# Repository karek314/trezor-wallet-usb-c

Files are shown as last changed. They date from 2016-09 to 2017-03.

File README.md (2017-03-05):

# Trezor Wallet USB-C
USB-C version of trezor hardware wallet designed to a bigger case

This is hardware project of forked <a href="https://github.com/trezor/trezor-hw">trezor-hw repository</a> redesigned to work with USB-C and a little bigger case.

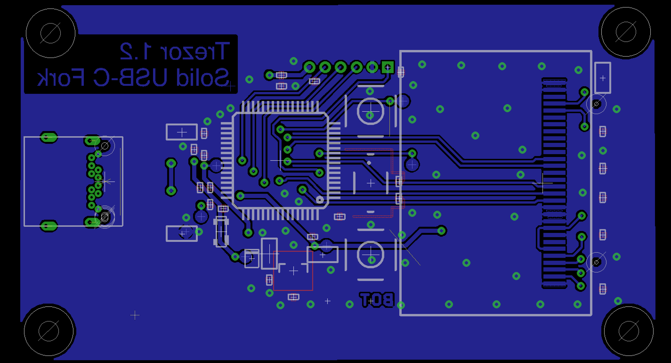
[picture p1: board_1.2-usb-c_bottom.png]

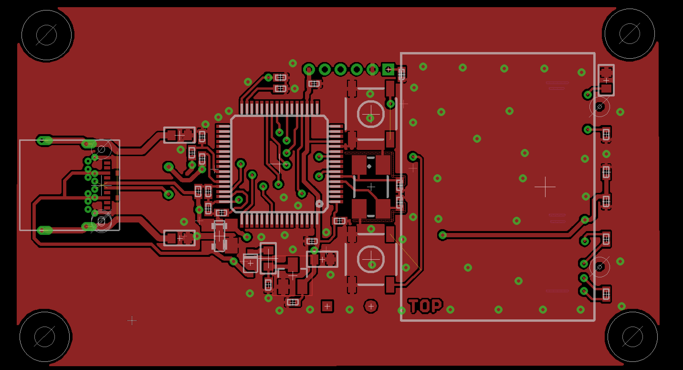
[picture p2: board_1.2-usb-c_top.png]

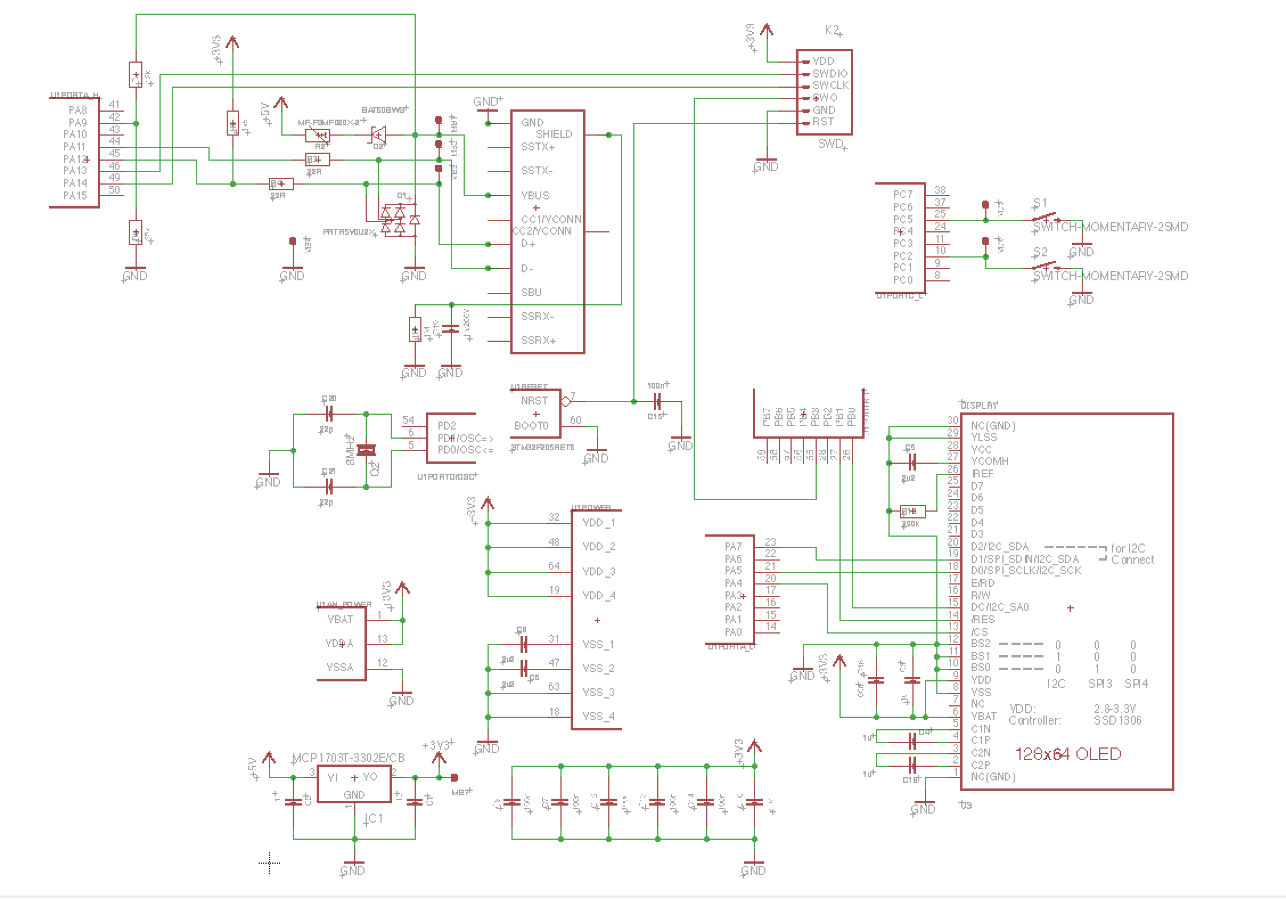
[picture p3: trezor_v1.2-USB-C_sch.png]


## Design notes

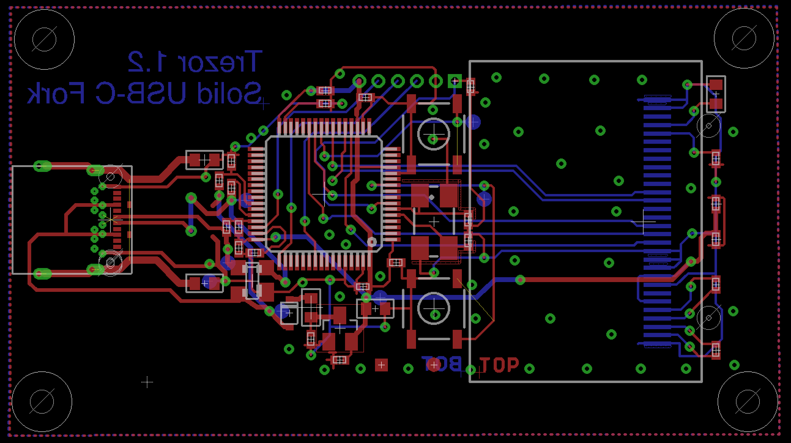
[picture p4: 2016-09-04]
trezor_v1.2-USB-C.png

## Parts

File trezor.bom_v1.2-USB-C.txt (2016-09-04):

Trezor
======

- 5x SMD 0603 Capacitor 1uF - C1, C2, C4, C10, C11
- 7x SMD 0603 Capacitor 0.1uF - C3, C12, C13, C14, C15, C16, C18
- 3x SMD 0603 Capacitor 2.2uF - C6, C7, C17
- 1x SMD 0603 Capacitor 4.7uF - C5
- 2x SMD 0603 Capacitor 22pF - C8, C9

- 1x SMD 0603 Resistor 390k - R1

- 2x Microbuton P-B17310
  * http://www.gme.cz/mikrospinace-do-dps/p-b17310-p630-143/

- 1x Micro USB (type B) Receptacle Bottom
  * http://cz.farnell.com/molex/47346-0001/micro-usb-type-b-receptacle-bottom/dp/1568026

- 1x OLED display 128x64 UG-2864HSWEG01
  * http://www.wide.hk/products.php?product=128X64-OLED-LED-Display-Module-SSD1306-%28White-Color%29

- 1x STM32F205RE
  * http://www.st.com/web/catalog/mmc/FM141/SC1169/SS1575/LN1433/PF245096
  * http://cz.farnell.com/stmicroelectronics/stm32f205ret6/ic-mcu-32bit-arm-64-lqfp/dp/2060897

- 1x MCP1703 Low Dropout Voltage Regulator
  * http://www.microchip.com/wwwproducts/Devices.aspx?dDocName=en530838
  * http://cz.farnell.com/microchip/mcp1703t-3302e-cb/v-reg-ldo-250ma-3-3v-sot-23a-3/dp/1439518

- 1x ABMM2 8 MHz Crystal
  * http://cz.farnell.com/abracon/abmm2-8-000mhz-e2-t/crystal-8m-18pf-cl-6x3-6mm-smt/dp/1611803

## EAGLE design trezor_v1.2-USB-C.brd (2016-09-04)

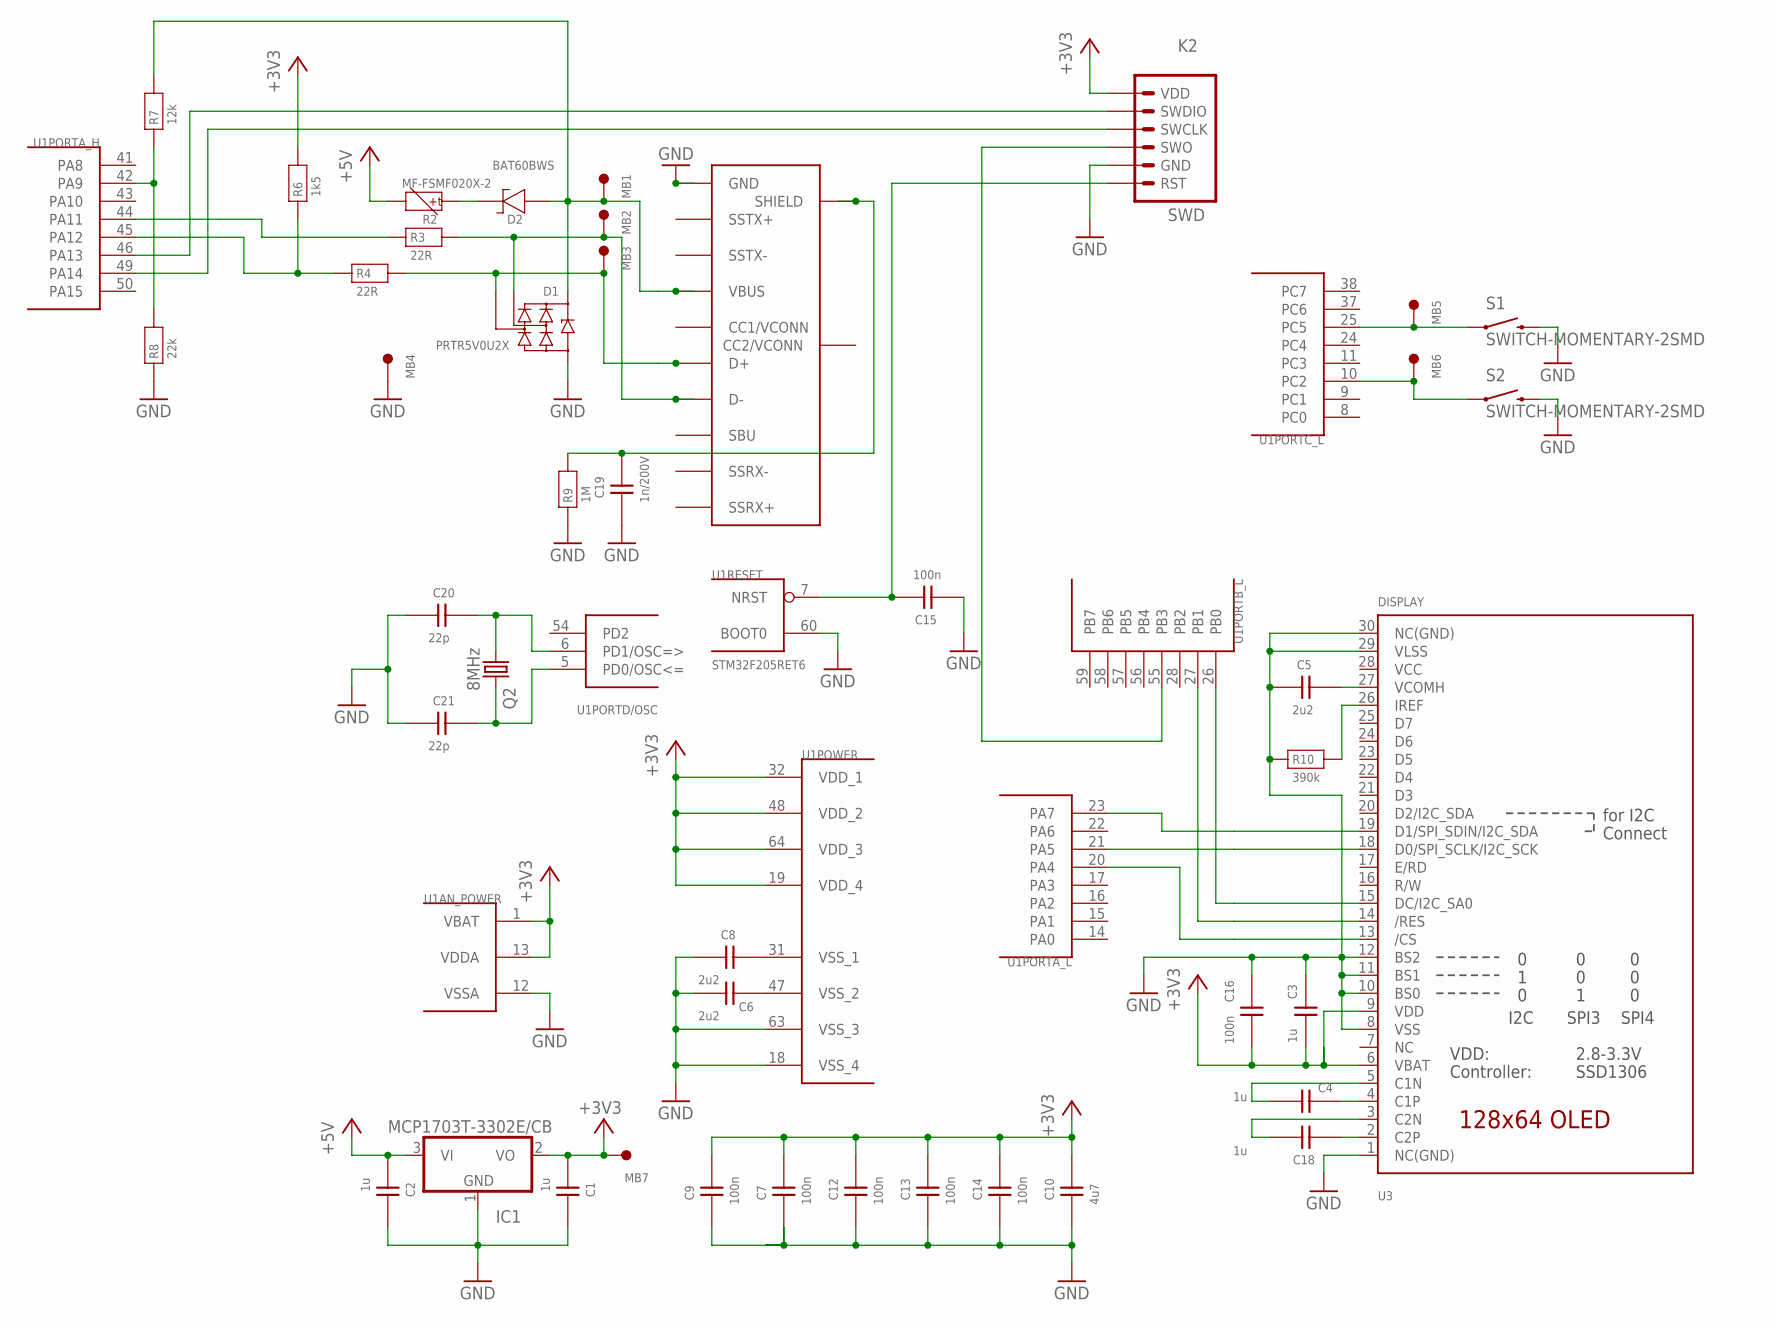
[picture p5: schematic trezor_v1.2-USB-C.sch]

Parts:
C1, C2, C3, C4, C18: 1u; 0402
C5: 2u2; 0603
C6, C8: 2u2; 0402
C7, C9, C12, C13, C14, C15, C16: 100n; 0402
C10: 4u7; 0603
C19: 1n/200V; 0603
C20, C21: 22p; 0402
D1: PRTR5V0U2X; SOT143B
D2: BAT60BWS; SOD323
IC1: MCP1703T-3302E/CB; SOT23
K2: SWD
MB1, MB2, MB3, MB4, MB5, MB6, MB7: MB_1.50; MB1.5
Q2: 8MHz; CTS406
R2: MF-FSMF020X-2; 0603
R3, R4: 22R; 0402
R6: 1k5; 0402
R7: 12k; 0402
R8: 22k; 0402
R9: 1M; 0603
R10: 390k; 0402
S1, S2: SWITCH-MOMENTARY-2SMD; TACTILE_SWITCH_SMD
U1: STM32F205RET6; TQFP64
U3: DISPLAY; UG-2864HSWEG01_0.96IN_WRAPAROUND
U$1: USB-TYPE-CHYBRID; USB-TYPE-C-HYBRID

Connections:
+3V3: C1.P$1 (1), C3.P$1 (1), C7.P$2 (2), C9.P$2 (2), C10.2, C12.P$2 (2), C13.P$2 (2), C14.P$2 (2), C16.P$1 (1), IC1.2 (VO), K2.6 (VDD), MB7.1, R6.P$2 (2), U1.1 (VBAT), U1.13 (VDDA), U1.19 (VDD_4), U1.32 (VDD_1), U1.48 (VDD_2), U1.64 (VDD_3), U3.6 (VBAT), U3.9 (VDD)
+5V: C2.P$1 (1), IC1.3 (VI), R2.2
GND: C1.P$2 (2), C2.P$2 (2), C3.P$2 (2), C5.1, C6.P$1 (1), C7.P$1 (1), C8.P$1 (1), C9.P$1 (1), C10.1, C12.P$1 (1), C13.P$1 (1), C14.P$1 (1), C15.P$1 (1), C16.P$2 (2), C19.1, C20.P$1 (1), C21.P$1 (1), D1.1 (GND), IC1.1 (GND), K2.2 (GND), MB4.1, R8.P$1 (1), R9.1, R10.P$1 (1), S1.3 (2), S1.4 (2), S2.3 (2), S2.4 (2), U1.12 (VSSA), U1.18 (VSS_4), U1.60 (BOOT0), U1.63 (VSS_3), U3.1 (NC(GND)), U3.8 (VSS), U3.10 (BS0), U3.11 (BS1), U3.12 (BS2), U3.29 (VLSS), U3.30 (NC(GND)), U$1.1 (GND), U$1.12 (GND), U$1.B1 (GND), U$1.B12 (GND)
unnamed: U1.23 (PA7), U3.19 (D1/SPI_SDIN/I2C_SDA)
unnamed: C15.P$2 (2), K2.1 (RST), U1.7 (NRST)
unnamed: U1.26 (PB0), U3.15 (DC/I2C_SA0)
unnamed: C8.P$2 (2), U1.31 (VSS_1)
unnamed: U1.21 (PA5), U3.18 (D0/SPI_SCLK/I2C_SCK)
unnamed: C5.2, U3.27 (VCOMH)
unnamed: U1.27 (PB1), U3.14 (/RES)
unnamed: C6.P$2 (2), U1.47 (VSS_2)
unnamed: R10.P$2 (2), U3.26 (IREF)
unnamed: C18.P$1 (1), U3.2 (C2P)
unnamed: C4.P$1 (1), U3.4 (C1P)
unnamed: C18.P$2 (2), U3.3 (C2N)
unnamed: C4.P$2 (2), U3.5 (C1N)
unnamed: K2.3 (SWO), U1.55 (PB3)
unnamed: K2.5 (SWDIO), U1.46 (PA13)
unnamed: U1.20 (PA4), U3.13 (/CS)
unnamed: K2.4 (SWCLK), U1.49 (PA14)
unnamed: R3.P$1 (1), U1.44 (PA11)
unnamed: MB5.1, S1.1, S1.2 (1), U1.25 (PC5)
unnamed: MB6.1, S2.1, S2.2 (1), U1.10 (PC2)
unnamed: D2.K (2), R2.1
unnamed: D1.2 (I/O1), MB2.1, R3.P$2 (2), U$1.7 (D-), U$1.B7 (D-)
unnamed: D1.3 (I/O2), MB3.1, R4.P$2 (2), U$1.6 (D+), U$1.B6 (D+)
unnamed: C19.2, R9.2, U$1.P$1 (SHIELD), U$1.P$2 (SHIELD), U$1.P$3 (SHIELD), U$1.P$4 (SHIELD), U$1.P$7 (SHIELD), U$1.P$8 (SHIELD), U$1.P$9 (SHIELD), U$1.P$10 (SHIELD), U$1.P$11 (SHIELD), U$1.P$12 (SHIELD), U$1.P$13 (SHIELD), U$1.P$14 (SHIELD), U$1.P$15 (SHIELD), U$1.P$16 (SHIELD), U$1.P$17 (SHIELD), U$1.P$18 (SHIELD), U$1.P$19 (SHIELD), U$1.P$20 (SHIELD), U$1.P$21 (SHIELD), U$1.P$22 (SHIELD), U$1.P$23 (SHIELD), U$1.P$24 (SHIELD), U$1.P$25 (SHIELD), U$1.P$26 (SHIELD), U$1.P$27 (SHIELD), U$1.P$28 (SHIELD), U$1.P$29 (SHIELD), U$1.P$30 (SHIELD), U$1.P$31 (SHIELD), U$1.P$32 (SHIELD), U$1.P$33 (SHIELD), U$1.P$34 (SHIELD), U$1.P$35 (SHIELD)
unnamed: R7.P$1 (1), R8.P$2 (2), U1.42 (PA9)
USB_D_P: R4.P$1 (1), R6.P$1 (1), U1.45 (PA12)
VBUS: D1.4 (VCC), D2.A (1), MB1.1, R7.P$2 (2), U$1.4 (VBUS), U$1.9 (VBUS), U$1.B4 (VBUS), U$1.B9 (VBUS)
VCC: U3.28 (VCC)
XTAL1: C20.P$2 (2), Q2.1, U1.6 (PD1/OSC=>)
XTAL2: C21.P$2 (2), Q2.3 (2), U1.5 (PD0/OSC<=)

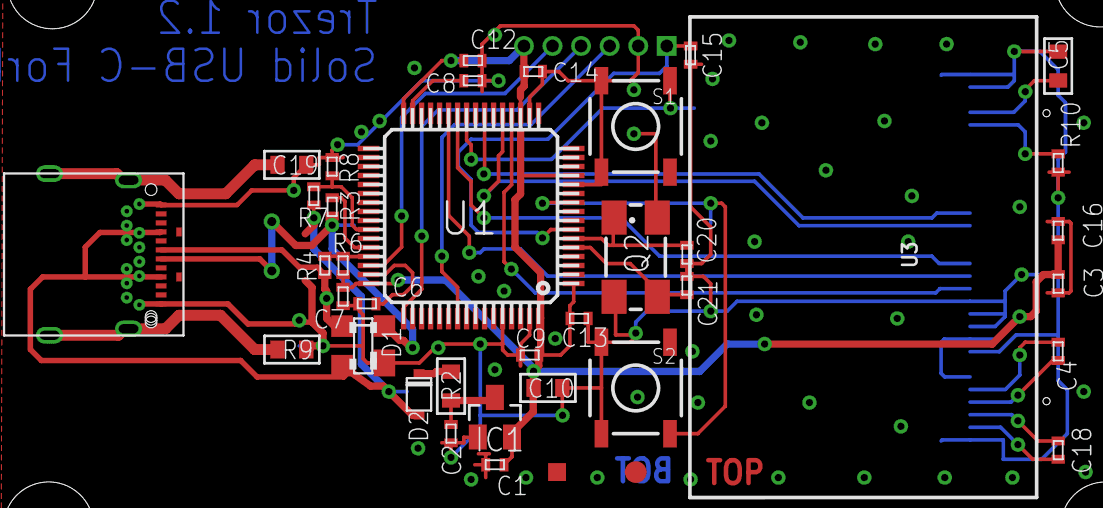
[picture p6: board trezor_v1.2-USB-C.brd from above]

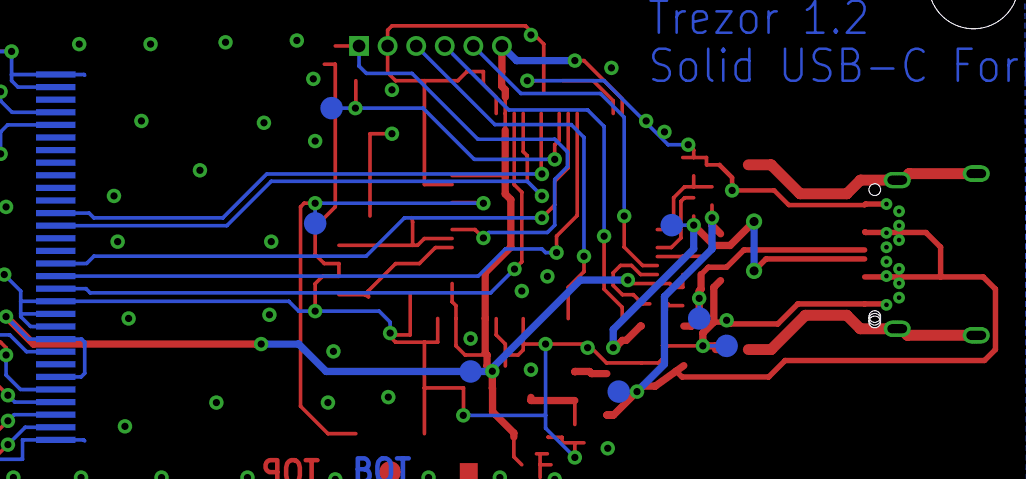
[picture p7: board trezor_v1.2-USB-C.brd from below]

Board: 2 copper layers, 46 parts (7 on the bottom side), 32 nets.

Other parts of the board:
U$3: BADMARK
U$4: CENTR

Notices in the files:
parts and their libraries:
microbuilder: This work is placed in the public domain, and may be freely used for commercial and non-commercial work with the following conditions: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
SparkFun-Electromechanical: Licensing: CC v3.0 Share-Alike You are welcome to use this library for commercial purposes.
